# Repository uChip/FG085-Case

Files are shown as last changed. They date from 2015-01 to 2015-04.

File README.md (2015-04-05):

Frequency Generator FG085 Case & Hack
=====================================

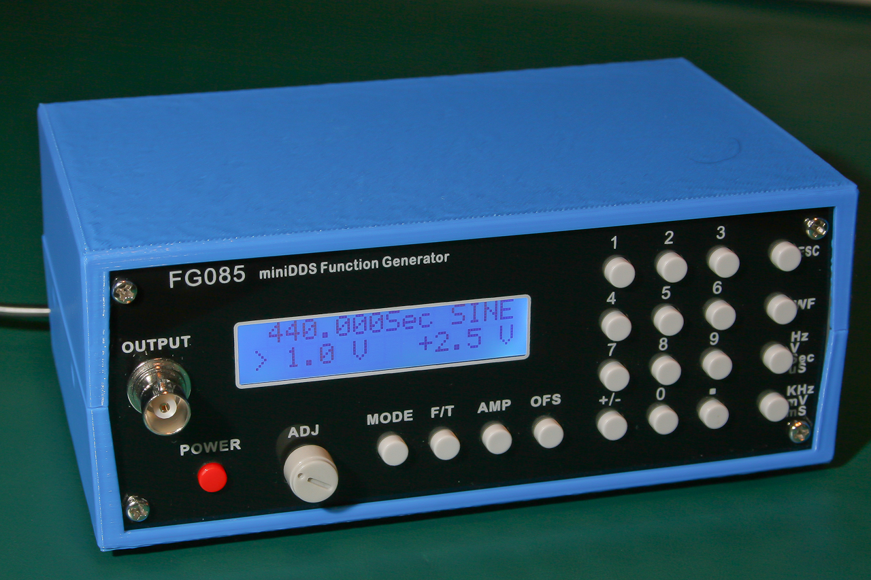
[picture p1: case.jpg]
FG085 Case
  
This repo contains a [.stl design file](https://github.com/uChip/FG085-Case/blob/master/FuncGenhalfcase1.1.stl) for 3D-printing a case for the [JYETech FG085 Frequency Generator kit](http://www.jyetech.com/Products/085/e085K.php).  The case uses the front panel and main board from the kit.  For the back panel you can use the kit part or there is a design file for a laser cut acrylic back panel with cutouts for bringing the power and USB connectors out the back.  See the [BOM file](https://github.com/uChip/FG085-Case/blob/master/BOM.md) for laser cutting service sources.  

This case design is a variation of the general purpose electronic project case design I did for the [StdBx project](http://www.github.com/StdBx/Series100).  The case is assembled from two identical half-case pieces.  See the BOM file for 3D printing service.  

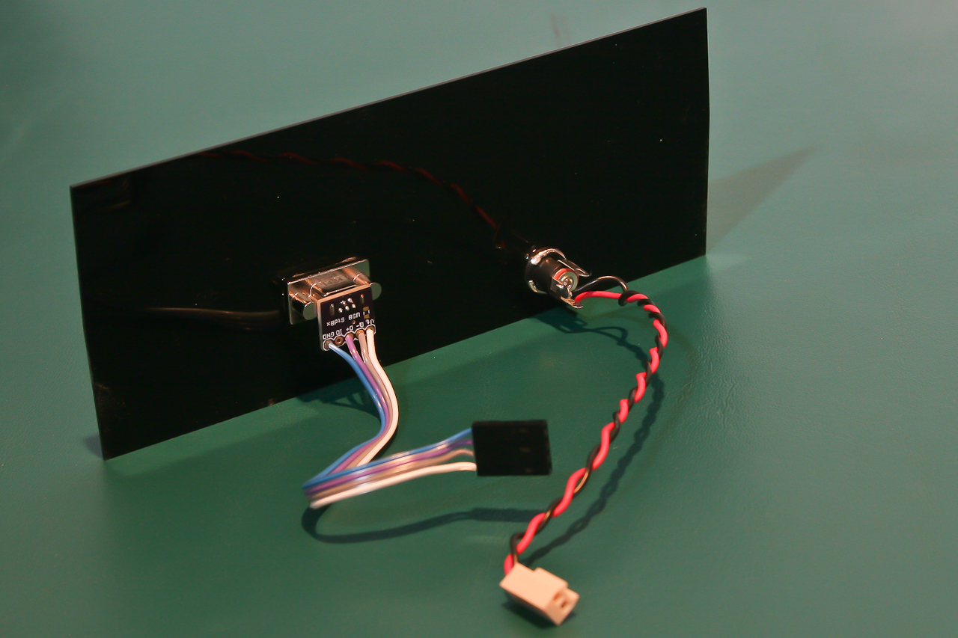
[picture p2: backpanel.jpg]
  
Hacking the kit:  I mostly assembled the kit per the instructions, but to bring the connectors out the back of the case I did modify a couple of things.  I also used different spacers so as to make case assembly easier.  The spacers are the same height, but are female-female instead of female-male so that the screws can go through mounting tabs in the case.  

The first mod is to install a polarized 2-pin header instead of the included barrel jack connector.  There are holes in the PCB for a 0.1" header already placed so this is easy.  Then just use a panel-mount barrel jack connector (see BOM for part #) and a wire pig-tail back to the PCB power header (also in BOM).  

The second mod is to install a 4-pin header for the USB.  Again, the PCB is already layed out for the header.  My board has both the PCB-mount USB connector and the header.  On the back panel I used a panel mount ruggedized USB mini-B connector.  I had to make a little PCB to breakout the USB connector to a ribbon cable (OSH Park order number and Eagle board file included in BOM) which then runs back to the PCB USB header.  

If you are looking for replacement switches, I have found some that fit and work.  See the BOM file.  

STATUS: As the photos show this project is complete and working.  It went together without too much trouble but there are a couple of things I would change if I did it again.  I sized the channel in the case for the thickness of the back panel in the kit, but then had a new back panel laser cut from 1/16" acrylic.  The new panel is thinner than to one in the kit and therefore a bit more flimsy than I would like.  The one in the kit is just slightly thicker and stiffer and will fit the channel if you want to cut the connector holes yourself.  If I were to make another one, I would widen the channel and cut the back panel from 1/8" acrylic.  Also the back panel design is just a bit too long for the case channel.  Literally just a few seconds of sanding one end will make it fit smoothly, but if I were to make another one I would shorten the length just a little.  

LICENSE: You are free to use this information however you like, but no liability is accepted.

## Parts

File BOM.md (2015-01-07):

#FG085 Case & Hack Bill of Materials (BOM)

###Case (half-case, order 2 pieces)  
I have had luck ordering 3D prints from [Shapeways](http://www.shapeways.com) and [MakeXYZ](http://www.makexyz.com).  Shapeways is more expensive but produces a more finished looking print.  More specifically at MakeXYZ I have used a local printer, [Jimmy Fakhouri](http://www.makexyz.com/printer/jimmyjack11@yahoo.com?printer=2771debf5bc034849d631421dd2aa280), to make several cases.  I highly recommend him.  

###Case Screws (4)  
The top and bottom halves of the case are held together with four #4 flat-head sheet-metal screws.

###Back Panel (1)  
There are three options for the back panel.  
  1. Use the back panel included with the kit.  You will have to cut holes for the power and USB connectors if you want to add them.  
  2. Use the enclosed [.dxf file](https://github.com/uChip/FG085-Case/blob/master/BackPanel1pc.DXF) to order a back panel in 1/16" black acrylic from a laser cutting company such as [Pololu](http://www.customlasercutting.com/).  This part will fit in the enclosed case design.  
  3. Use the enclosed [.dxf file](https://github.com/uChip/FG085-Case/blob/master/BackPanel1pc.DXF) to order a back panel in 1/8" black acrylic from a laser cutting company such as [Pololu](http://www.customlasercutting.com/).  You will need to modify the case .stl file to make the channel that captures the back panel wide enough for the 1/8" acrylic.  

###Spacers (4)  
Digi-KEY #952-2313-ND HEX STANDOFF M3 BRASS 12MM  
Use these spacers instead of the ones included in the kit.  They go between the front panel and the PCB.  Use the screws included in the kit.  The screws that normally retain the back panel will now secure the PCB/front panel assembly into the case.  You will only be able to put in two screws in the case but that is sufficient.

###Rubber Feet, stick-on (4)  
Digi-Key #SJ5003-0-ND BUMPER CYLINDRICAL 0.44" DIA BLK  

###USB pig-tail  
Note that although I used a plug/header to connect to the PCB, you could just solder the ribbon cable directly to the board.  
  - USB mini-B Connector (1)  Digi-Key #MUSBB55104 CONN RUGGED USB RCPT VERT MINI B  
  - Connector screws (2) Digi-Key #H700-ND MACHINE SCREW PAN PHILLIPS 2-56  
  - Breakout PCB (1)  [OSH Park shared project #tosjrsDY](https://oshpark.com/shared_projects/tosjrsDY)  
  - Ribbon Cable (6")  4-conductor, 28 AWG
  - 4-pin Housing (1)  Digi-Key #952-2229-ND SIL FEMALE CRIMP HOUSING 4POS  
  - Crimp Pins (4 plus spares)  Digi-Key #952-2157-1-ND FEMALE CRIMP CONTACT SELECTIVE
  - 4-pin Break-away Header, 0.1" (one length of header at least 4 pins)  

###Power pig-tail  
Note that although I used a plug/header to connect to the PCB, you could just solder the wires directly to the board.  
  - Barrel Jack Connector, Panel Mount (1)  Digi-Key #CP-5-ND CONN 2.1MM JACK w/HARD PNL MNT
  - Wire (8" red, 8" black)  stranded, 24 AWG
  - 2-Pin Polarized Housing (1)  [SparkFun #PRT-08095](https://www.sparkfun.com/products/8095)
  - Crimp Pins (2 plus spares)  [SparkFun #PRT-08100](https://www.sparkfun.com/products/8100)
  - 2-Pin Polarized Header (1)  [SparkFun #PRT-08233](https://www.sparkfun.com/products/8233)

###Push-Button Switches  
None are required but if you are looking to replace some of the ones in the kit or to use in another project you can find them at [Mouser](http://www.mouser.com) #612-TL2230-OA.

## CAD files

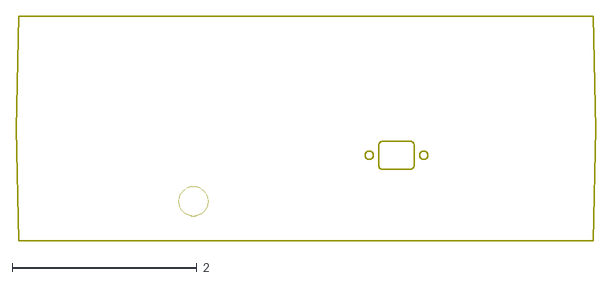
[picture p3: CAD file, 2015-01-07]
BackPanel1pc.DXF
6.28 x 2.44

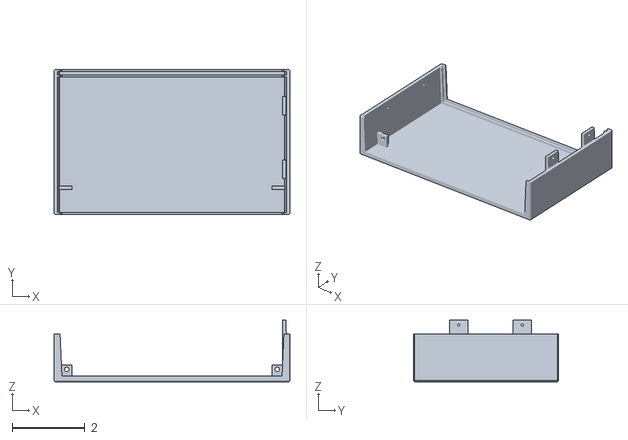
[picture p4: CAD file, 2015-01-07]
FuncGenhalfcase1.1.stl
6.50 x 4.00 x 1.70

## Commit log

2015-01-07 First Commit of files
    [BackPanel1pc.DXF, FuncGenhalfcase1.1.stl, USB StdBx.brd]
2015-01-07 Started BOM. README edits.
2015-01-07 BOM & README edits
2015-01-07 BOM edits
2015-02-12 adding photos of case and back panel
